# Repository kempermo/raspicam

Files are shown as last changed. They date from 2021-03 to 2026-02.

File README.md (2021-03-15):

# raspiCAM

### Setup WiFi
In order to setup WiFi with the correct credentials open the attached file "wpa_supplicant.conf" with a text editor and fill in the correct ssid and password that matches your WiFi setup.

Insert the sd-card from raspi into your computer and open it in the finder. Place the generated "wpa_supplicant.conf" onto the card.

Insert the card back to the raspi and boot. The raspi should now boot and connect to the new WiFi.

### Helpful applications
LanScan for getting the IP address of the raspi - https://apps.apple.com/de/app/lanscan/id472226235?mt=12

### Credetials for login through ssh
User: pi
Passwort: user

### Terminal command for initializing the ssh connection
ssh pi@192.168.20.248 (replace with the proper IP address of your raspi)

### Helpful terminal commands
ls - List current directory contents
cd + ... - entering a directory
cd .. - going back one directory
sudo nano + ... - opening a file in editor
sudo python3 + ... - running a python script with python3
ps aux - list current running processes
sudo kill 425 - kill the process with ID 425

### Helpful key commands
"option"+"c" - quit the current running process

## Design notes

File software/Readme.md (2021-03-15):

Last login: Sat Mar 13 20:49:38 on ttys001
mke@Bridge ~ % ssh pi@192.168.20.248         
pi@192.168.20.248's password: 
Linux raspberrypi 5.4.51+ #1333 Mon Aug 10 16:38:02 BST 2020 armv6l

The programs included with the Debian GNU/Linux system are free software;
the exact distribution terms for each program are described in the
individual files in /usr/share/doc/*/copyright.

Debian GNU/Linux comes with ABSOLUTELY NO WARRANTY, to the extent
permitted by applicable law.
Last login: Sat Mar 13 22:19:36 2021
pi@raspberrypi:~ $ ps aux
USER       PID %CPU %MEM    VSZ   RSS TTY      STAT START   TIME COMMAND
root         1  0.3  2.1  32704  8024 ?        Ss   15:35   0:08 /sbin/init splash
root         2  0.0  0.0      0     0 ?        S    15:35   0:00 [kthreadd]
root         5  0.0  0.0      0     0 ?        I    15:35   0:00 [kworker/u2:0-brcmf_wq/mmc1:0001:1]
root         6  0.0  0.0      0     0 ?        I<   15:35   0:00 [mm_percpu_wq]
root         7  0.0  0.0      0     0 ?        S    15:35   0:01 [ksoftirqd/0]
root         8  0.0  0.0      0     0 ?        S    15:35   0:00 [kdevtmpfs]
root         9  0.0  0.0      0     0 ?        I<   15:35   0:00 [netns]
root        11  0.0  0.0      0     0 ?        S    15:35   0:00 [khungtaskd]
root        12  0.0  0.0      0     0 ?        S    15:35   0:00 [oom_reaper]
root        13  0.0  0.0      0     0 ?        I<   15:35   0:00 [writeback]
root        14  0.0  0.0      0     0 ?        S    15:35   0:00 [kcompactd0]
root        28  0.0  0.0      0     0 ?        I<   15:35   0:00 [kblockd]
root        29  0.0  0.0      0     0 ?        I<   15:35   0:00 [blkcg_punt_bio]
root        30  0.0  0.0      0     0 ?        S    15:35   0:00 [watchdogd]
root        31  0.0  0.0      0     0 ?        I<   15:35   0:00 [rpciod]
root        32  0.0  0.0      0     0 ?        I<   15:35   0:00 [kworker/u3:0-hci0]
root        33  0.0  0.0      0     0 ?        I<   15:35   0:00 [xprtiod]
root        34  0.0  0.0      0     0 ?        S    15:35   0:00 [kswapd0]
root        35  0.0  0.0      0     0 ?        I<   15:35   0:00 [nfsiod]
root        36  0.0  0.0      0     0 ?        I<   15:35   0:00 [iscsi_eh]
root        37  0.0  0.0      0     0 ?        I<   15:35   0:00 [dwc_otg]
root        38  0.0  0.0      0     0 ?        I<   15:35   0:00 [DWC Notificatio]
root        40  0.1  0.0      0     0 ?        S<   15:35   0:02 [vchiq-slot/0]
root        41  0.0  0.0      0     0 ?        S<   15:35   0:00 [vchiq-recy/0]
root        42  0.0  0.0      0     0 ?        S<   15:35   0:00 [vchiq-sync/0]
root        43  0.0  0.0      0     0 ?        S    15:35   0:00 [vchiq-keep/0]
root        44  0.0  0.0      0     0 ?        S<   15:35   0:00 [SMIO]
root        46  0.0  0.0      0     0 ?        I<   15:35   0:00 [mmc_complete]
root        47  0.0  0.0      0     0 ?        I<   15:35   0:01 [kworker/0:1H-mmc_complete]
root        49  0.0  0.0      0     0 ?        S    15:35   0:00 [jbd2/mmcblk0p2-]
root        50  0.0  0.0      0     0 ?        I<   15:35   0:00 [ext4-rsv-conver]
root        51  0.0  0.0      0     0 ?        I<   15:35   0:00 [ipv6_addrconf]
root        77  0.0  1.7  15528  6588 ?        Ss   15:35   0:02 /lib/systemd/systemd-journald
root       108  0.0  1.0  18360  3832 ?        Ss   15:35   0:01 /lib/systemd/systemd-udevd
root       122  0.0  0.0      0     0 ?        S<   15:36   0:00 [SMIO]
root       127  0.0  0.0      0     0 ?        I<   15:36   0:00 [mmal-vchiq]
root       128  0.0  0.0      0     0 ?        I<   15:36   0:00 [mmal-vchiq]
root       130  0.0  0.0      0     0 ?        I<   15:36   0:00 [mmal-vchiq]
root       139  0.0  0.0      0     0 ?        I<   15:36   0:00 [mmal-vchiq]
root       140  0.0  0.0      0     0 ?        I<   15:36   0:00 [mmal-vchiq]
root       141  0.0  0.0      0     0 ?        I<   15:36   0:00 [mmal-vchiq]
root       164  0.0  0.0      0     0 ?        I<   15:36   0:00 [cfg80211]
root       165  0.0  0.0      0     0 ?        I<   15:36   0:00 [brcmf_wq/mmc1:0]
root       166  0.0  0.0      0     0 ?        S    15:36   0:00 [brcmf_wdog/mmc1]
systemd+   221  0.0  1.4  22396  5604 ?        Ssl  15:36   0:01 /lib/systemd/systemd-timesyncd
root       263  0.1  0.0      0     0 ?        S    15:36   0:03 [irq/160-gt911]
root       266  0.0  0.6   7932  2300 ?        Ss   15:36   0:00 /usr/sbin/cron -f
message+   287  0.0  0.9   6712  3636 ?        Ss   15:36   0:01 /usr/bin/dbus-daemon --system --address=s
root       292  0.0  0.3  27640  1428 ?        SLsl 15:36   0:00 /usr/sbin/rngd -r /dev/hwrng
root       301  0.0  0.5   2816  1944 ?        Ss   15:36   0:00 /sbin/dhcpcd -q -b
root       311  0.0  1.2  10724  4640 ?        Ss   15:36   0:00 /sbin/wpa_supplicant -u -s -O /run/wpa_su
avahi      319  0.1  0.7   5888  3012 ?        Ss   15:36   0:03 avahi-daemon: running [raspberrypi.local]
root       330  0.0  0.5   3676  2004 ?        SNs  15:36   0:00 /usr/sbin/alsactl -E HOME=/run/alsa -s -n
avahi      340  0.0  0.4   5756  1572 ?        S    15:36   0:00 avahi-daemon: chroot helper
root       341  0.0  2.4  60128  9364 ?        Ssl  15:36   0:01 /usr/lib/udisks2/udisksd
root       344  0.0  1.5  13024  5864 ?        Ss   15:36   0:00 /lib/systemd/systemd-logind
nobody     352  0.0  0.5   4304  2116 ?        Ss   15:36   0:00 /usr/sbin/thd --triggers /etc/triggerhapp
root       356  0.0  0.9  24736  3536 ?        Ssl  15:36   0:00 /usr/sbin/rsyslogd -n -iNONE
root       376  0.0  1.1  10984  4280 ?        Ss   15:36   0:00 wpa_supplicant -B -c/etc/wpa_supplicant/w
root       379  0.0  1.5  36880  6016 ?        Ssl  15:36   0:00 /usr/lib/policykit-1/polkitd --no-debug
root       395  0.0  0.0      0     0 ?        I    15:36   0:01 [kworker/u2:3-brcmf_wq/mmc1:0001:1]
root       400  0.0  0.8  10348  3304 ?        S    15:36   0:00 sudo python3 /home/pi/Documents/camera/ca
root       404  0.0  0.1   2124   592 ?        S    15:36   0:00 /usr/bin/hciattach /dev/serial1 bcm43xx 3
root       406  0.0  0.0      0     0 ?        I<   15:36   0:00 [kworker/u3:2-hci0]
root       411  0.0  1.5  10708  5664 ?        Ss   15:36   0:00 /usr/sbin/sshd -D
root       415  0.0  0.7  21840  2764 ?        Sl   15:36   0:00 /usr/sbin/netatalk
root       416  0.2  2.6  57100 10044 ?        S    15:36   0:04 /usr/sbin/afpd -d -F /etc/netatalk/afp.co
root       417  0.0  1.1  10076  4156 ?        S    15:36   0:00 /usr/sbin/cnid_metad -d -F /etc/netatalk/
root       425 94.8  3.6  82592 13904 ?        Rl   15:36  35:11 python3 /home/pi/Documents/camera/cameraT
root       428  0.0  1.2   9792  4656 ?        Ss   15:36   0:00 /usr/lib/bluetooth/bluetoothd
root       433  0.0  1.5  36464  5904 ?        Ssl  15:36   0:00 /usr/sbin/lightdm
root       436  0.0  1.2  26692  4756 ?        Ssl  15:36   0:00 /usr/bin/bluealsa
root       451  0.0  0.0      0     0 ?        S<   15:36   0:00 [krfcommd]
root       500  0.1  9.4 117744 35704 tty7     Ssl+ 15:36   0:02 /usr/lib/xorg/Xorg :0 -seat seat0 -auth /
root       501  0.0  0.7   5604  2728 tty1     Ss   15:36   0:00 /bin/login -f
pi         561  0.0  1.9  14712  7424 ?        Ss   15:36   0:00 /lib/systemd/systemd --user
pi         565  0.0  0.9  16828  3436 ?        S    15:36   0:00 (sd-pam)
pi         634  0.0  0.9   8468  3704 tty1     S+   15:36   0:00 -bash
root       652  0.0  1.6  29892  6392 ?        Sl   15:36   0:00 lightdm --session-child 14 17
pi         660  0.0  3.1  54076 11932 ?        Ssl  15:36   0:00 /usr/bin/lxsession -s LXDE-pi -e LXDE
pi         669  0.0  0.9   6520  3444 ?        Ss   15:36   0:00 /usr/bin/dbus-daemon --session --address=
pi         693  0.0  0.3   4504  1404 ?        Ss   15:36   0:00 /usr/bin/ssh-agent x-session-manager
pi         710  0.0  1.6  42580  6228 ?        Ssl  15:36   0:00 /usr/lib/gvfs/gvfsd
pi         720  0.0  1.4  51548  5444 ?        Sl   15:36   0:00 /usr/lib/gvfs/gvfsd-fuse /run/user/1000/g
pi         738  0.0  3.8  62224 14452 ?        S    15:36   0:00 openbox --config-file /home/pi/.config/op
pi         742  0.0  2.9  47672 11192 ?        Sl   15:36   0:00 lxpolkit
pi         746  0.3  7.4 144540 28268 ?        Sl   15:36   0:07 lxpanel --profile LXDE-pi
pi         750  0.1  5.5  71092 21112 ?        Sl   15:36   0:02 pcmanfm --desktop --profile LXDE-pi
pi         778  0.0  0.3   4504  1300 ?        Ss   15:36   0:00 /usr/bin/ssh-agent -s
pi         808  0.0  2.7  78704 10356 ?        Ssl  15:37   0:00 /usr/lib/gvfs/gvfs-udisks2-volume-monitor
pi         815  0.0  1.4  39264  5320 ?        Ssl  15:37   0:00 /usr/lib/gvfs/gvfs-goa-volume-monitor
pi         819  0.0  1.9  54164  7260 ?        Ssl  15:37   0:00 /usr/lib/gvfs/gvfs-afc-volume-monitor
pi         824  0.0  1.5  40828  5968 ?        Ssl  15:37   0:00 /usr/lib/gvfs/gvfs-gphoto2-volume-monitor
pi         828  0.0  1.4  39252  5540 ?        Ssl  15:37   0:00 /usr/lib/gvfs/gvfs-mtp-volume-monitor
pi         839  0.0  1.9  51148  7292 ?        Sl   15:37   0:00 /usr/lib/gvfs/gvfsd-trash --spawner :1.4 
pi         855  0.0  1.3  26428  5068 ?        Sl   15:37   0:00 /usr/lib/menu-cache/menu-cached /run/user
root      1297  0.0  0.0      0     0 ?        I    15:59   0:00 [kworker/0:0-events_power_efficient]
root      1346  0.0  0.0      0     0 ?        I    16:04   0:00 [kworker/0:1-events]
root      1347  0.0  0.0      0     0 ?        I<   16:04   0:00 [kworker/0:0H]
root      1409  0.0  0.0      0     0 ?        I    16:09   0:00 [kworker/0:2-events]
root      1434  0.5  1.6  12220  6372 ?        Ss   16:12   0:00 sshd: pi [priv]
pi        1468  0.2  1.1  12220  4156 ?        S    16:12   0:00 sshd: pi@pts/0
pi        1471  1.1  0.9   8464  3704 pts/0    Ss   16:12   0:00 -bash
root      1482  0.0  0.0      0     0 ?        I<   16:12   0:00 [kworker/0:2H]
root      1483  0.0  0.0      0     0 ?        I    16:12   0:00 [kworker/u2:1-brcmf_wq/mmc1:0001:1]
pi        1484  0.0  0.6   9772  2552 pts/0    R+   16:13   0:00 ps aux
pi@raspberrypi:~ $ sudo kill 425
pi@raspberrypi:~ $ kill 425
-bash: kill: (425) - Kein passender Prozess gefunden
pi@raspberrypi:~ $ ls
Bookshelf  Desktop  Documents  Downloads  Music  Pictures  Pimoroni  Public  sketchbook  Templates  test.jpg  Videos
pi@raspberrypi:~ $ ls
Bookshelf  Desktop  Documents  Downloads  Music  Pictures  Pimoroni  Public  sketchbook  Templates  test.jpg  Videos
pi@raspberrypi:~ $ cd Documents
pi@raspberrypi:~/Documents $ ls
camera
pi@raspberrypi:~/Documents $ cd camera
pi@raspberrypi:~/Documents/camera $ ls
 cameraTest.py                           'IMG_2020-12-29 21:21:28.433020_2_.jpg'  'pic_2020-12-28 22:55:26.054270_3_.jpg'
 grid.png                                'IMG_2020-12-29 21:21:28.433020_3_.jpg'  'pic_2020-12-28 22:55:26.054270_4_.jpg'
 IMG_2020-12-29_0_.jpg                    lib_oled96                              'pic_2020-12-28 22:56:33.998395_0_.jpg'
 IMG_2020-12-29_1_.jpg                   'pic2020-12-28 22:48:20.859667.jpg'      'pic_2020-12-28 22:56:33.998395_1_.jpg'
'IMG_2020-12-29 20:57:09.884041_0_.jpg'  'pic2020-12-28 22:52:31.490010.jpg'       picameraPygame.py
'IMG_2020-12-29 21:15:53.772426_0_.jpg'  'pic_2020-12-28 22:55:26.054270_0_.jpg'   python-multitouch
'IMG_2020-12-29 21:21:28.433020_0_.jpg'  'pic_2020-12-28 22:55:26.054270_1_.jpg'   stats.py
'IMG_2020-12-29 21:21:28.433020_1_.jpg'  'pic_2020-12-28 22:55:26.054270_2_.jpg'   stats.py.save
pi@raspberrypi:~/Documents/camera $ cd ..
pi@raspberrypi:~/Documents $ cd camera
pi@raspberrypi:~/Documents/camera $ sudo nano cameraTest.py
pi@raspberrypi:~/Documents/camera $ sudo nano cameraTest.py
pi@raspberrypi:~/Documents/camera $ sudo python3 cameraTest.py
^CTraceback (most recent call last):
  File "cameraTest.py", line 79, in <module>
    disp.image(image)
  File "/usr/local/lib/python3.7/dist-packages/adafruit_framebuf.py", line 445, in image
    self.pixel(x, y, 1)  # only write if pixel is true
  File "/usr/local/lib/python3.7/dist-packages/adafruit_framebuf.py", line 248, in pixel
    self.format.set_pixel(self, x, y, color)
  File "/usr/local/lib/python3.7/dist-packages/adafruit_framebuf.py", line 92, in set_pixel
    framebuf.buf[index] = (framebuf.buf[index] & ~(0x01 << offset)) | (
KeyboardInterrupt
pi@raspberrypi:~/Documents/camera $ sudo python3 cameraTest.py
^CTraceback (most recent call last):
  File "cameraTest.py", line 80, in <module>
    disp.show()
  File "/usr/local/lib/python3.7/dist-packages/adafruit_ssd1306.py", line 194, in show
    self.write_framebuf()
  File "/usr/local/lib/python3.7/dist-packages/adafruit_ssd1306.py", line 261, in write_framebuf
    self.i2c_device.write(self.buffer)
  File "/usr/local/lib/python3.7/dist-packages/adafruit_bus_device/i2c_device.py", line 84, in write
    self.i2c.writeto(self.device_address, buf, start=start, end=end)
  File "/usr/local/lib/python3.7/dist-packages/busio.py", line 115, in writeto
    return self._i2c.writeto(address, memoryview(buffer)[start:end], stop=stop)
  File "/usr/local/lib/python3.7/dist-packages/adafruit_blinka/microcontroller/generic_linux/i2c.py", line 49, in writeto
    self._i2c_bus.write_bytes(address, buffer[start:end])
  File "/usr/local/lib/python3.7/dist-packages/Adafruit_PureIO/smbus.py", line 308, in write_bytes
    self._device.write(buf)
KeyboardInterrupt
pi@raspberrypi:~/Documents/camera $ sudo nano example.py
pi@raspberrypi:~/Documents/camera $ ls
 cameraTest.py                           'IMG_2020-12-29 21:21:28.433020_2_.jpg'  'pic_2020-12-28 22:55:26.054270_3_.jpg'
 grid.png                                'IMG_2020-12-29 21:21:28.433020_3_.jpg'  'pic_2020-12-28 22:55:26.054270_4_.jpg'
 IMG_2020-12-29_0_.jpg                    lib_oled96                              'pic_2020-12-28 22:56:33.998395_0_.jpg'
 IMG_2020-12-29_1_.jpg                   'pic2020-12-28 22:48:20.859667.jpg'      'pic_2020-12-28 22:56:33.998395_1_.jpg'
'IMG_2020-12-29 20:57:09.884041_0_.jpg'  'pic2020-12-28 22:52:31.490010.jpg'       picameraPygame.py
'IMG_2020-12-29 21:15:53.772426_0_.jpg'  'pic_2020-12-28 22:55:26.054270_0_.jpg'   python-multitouch
'IMG_2020-12-29 21:21:28.433020_0_.jpg'  'pic_2020-12-28 22:55:26.054270_1_.jpg'   stats.py
'IMG_2020-12-29 21:21:28.433020_1_.jpg'  'pic_2020-12-28 22:55:26.054270_2_.jpg'   stats.py.save
pi@raspberrypi:~/Documents/camera $ sudo nano cameraTest.py

  GNU nano 3.2                                              cameraTest.py                                              Verändert  

from picamera import PiCamera
from time import sleep
from datetime import datetime
import smbus #needed for i2c communication to arduino
from ft5406 import Touchscreen
from board import SCL, SDA #another i2c library needed to interface with the small oled
import busio #i2c for small oled
from PIL import Image, ImageDraw, ImageFont #small oled
import adafruit_ssd1306 #small oled

bus =  smbus.SMBus(11)
address = 0x08 #refering to the address of the arduino

#small oled
# Create the I2C interface.
i2c = busio.I2C(SCL, SDA)
# to the right size for your display!
disp = adafruit_ssd1306.SSD1306_I2C(128, 32, i2c)

# Clear display.
disp.fill(0)
disp.show()

width = disp.width
height = disp.height
image = Image.new("1", (width, height))

# Get drawing object to draw on image.
draw = ImageDraw.Draw(image)

font = ImageFont.load_default()

camera = PiCamera()

shutterFlag = True

timestamp=datetime.now().date()
pictureIndex = 0

ts = Touchscreen(device="Goodix Capacitive TouchScreen")

def picture():
        camera.capture('IMG_'+str(timestamp)+'_'+str(pictureIndex)+'_'+'.jpg') #taking the picture

def translate(value, leftMin, leftMax, rightMin, rightMax):
    # Figure out how 'wide' each range is
    leftSpan = leftMax - leftMin
    rightSpan = rightMax - rightMin

    # Convert the left range into a 0-1 range (float)
    valueScaled = float(value - leftMin) / float(leftSpan)

    # Convert the 0-1 range into a value in the right range.
    return rightMin + (valueScaled * rightSpan)

camera.rotation = 270
camera.start_preview()
camera.preview_window = (0,0,800,480)
#camera.annotate_text = "Effect: Information"

while shutterFlag:
        draw.rectangle((0, 0, width, height), outline=0, fill=0)
        number = bus.read_byte(address)
        draw.text((0, 0), "Number: " + str(pictureIndex), font=font, fill=255)
        draw.text((0, 8), "Brightness: " + str(camera.brightness), font=font, fill=255)
        draw.text((0, 16), "Contrast: " + str(camera.contrast), font=font, fill=255)
        for touch in ts.poll():
                #print(touch.slot, touch.id, touch.valid, touch.x, touch.y)
                if touch.slot == 0:
                        camera.brightness = int(translate(touch.x,0,800,0,100))
                        camera.contrast = int(translate(touch.y,0,480,-100,100))
                if touch.slot == 1 and touch.valid == True:
                        camera.saturation = int(translate(touch.x,0,800,-100,100))
        if number == 0:
                print("read", number)
                picture()
                pictureIndex+=1
                sleep(1)
        disp.image(image)
        disp.show()
#camera.stop_preview()

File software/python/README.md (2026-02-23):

# raspiCAM – Python Software

## Hardware

| Component | Details |
|---|---|
| Raspberry Pi | Pi 4 / Pi Zero 2 W |
| Display | HyperPixel 4.0 (480×800, DRM/KMS) |
| Camera | OV5647 (connected via CSI) |
| Small OLED | 128×32 SSD1306 via I2C |
| Arduino | I2C address `0x08`, connected on bus 11 |

---

## Files

| File | Purpose |
|---|---|
| `bareMinimum.py` | Main camera application |
| `camera.service` | systemd service for autostart |
| `99-i2c-alias.rules` | udev rule to fix I2C bus numbering |

---

## Raspberry Pi Setup

### 1. Boot mode
The app uses `Preview.DRM` which requires **exclusive access to the display**.
Boot the Pi to **CLI** (not desktop):
```
sudo raspi-config nonint do_boot_behaviour B2
```

### 2. I2C bus alias (persistent)
On Raspberry Pi OS Bookworm the I2C bus is numbered `i2c-11` instead of the expected `i2c-1`. The udev rule creates a persistent symlink automatically on every boot:

```bash
sudo cp 99-i2c-alias.rules /etc/udev/rules.d/
sudo udevadm control --reload-rules
```

### 3. Autostart via systemd
Install the service so the camera starts automatically on every boot:

```bash
sudo cp camera.service /etc/systemd/system/
sudo systemctl daemon-reload
sudo systemctl enable camera.service
sudo systemctl start camera.service
```

Check status:
```bash
sudo systemctl status camera.service
```

View logs:
```bash
sudo journalctl -u camera.service -n 50
```

---

## Running manually

```bash
python3 /home/pi/Documents/camera/bareMinimum.py
```

Required files on the Pi at `/home/pi/Documents/camera/`:
- `bareMinimum.py`
- `uiImage.png` (UI overlay, 480×800 RGBA)
- `ESKlarheitGrotesk-Bold.ttf` (font for OLED display)

---

## Known issues & notes

- **I2C bus renumbering** – Pi OS Bookworm renamed `i2c-1` to `i2c-11`. The udev rule in this repo handles this automatically.
- **DRM preview + desktop conflict** – `Preview.DRM` takes exclusive control of the display. If a Wayland compositor (labwc) is running it will conflict and the preview will be invisible. Always boot to CLI.
- **Color format** – The camera stream must be configured as `XRGB8888`. Using the default `XBGR8888` results in red and blue channels being swapped on the HyperPixel display.
- **systemd WorkingDirectory** – The service requires `WorkingDirectory=/home/pi` so that `lgpio` can create its temporary notification files. Without this the service crashes silently in a restart loop.

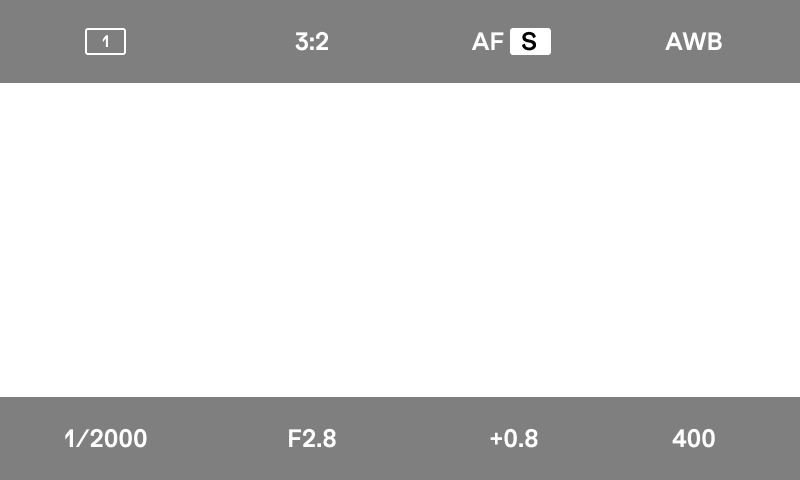
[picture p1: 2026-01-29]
software/python/uiImage.png

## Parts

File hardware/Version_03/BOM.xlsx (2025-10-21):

Check | Qty | Part | Value | Type | URL
 | 5 | C1,C6,C8,C9,C10 | 10uF | Cap | https://www.mouser.de/ProductDetail/KEMET/C0805C106M8PACTU?qs=Zpyg6gQUYs10fYWfqjpq2Q%3D%3D
 | 1 | C2 | 2.2uF | Cap
 | 2 | C3,C7 | 1uF | Cap | https://www.mouser.de/ProductDetail/KEMET/C0805C105K8RACTU?qs=Nnkldhwoc37vJEa%2FkGSWlQ%3D%3D
 | 4 | C4,C11,C12,C13 | 0.1uF | Cap
 | 1 | C5 | 100uF | Cap
 | 2 | R1,R3 | 1.87mOhm | Res
 | 2 | R2,R13 | 340kOhm | Res
 | 1 | R4 | 200kOhm | Res
 | 1 | R8 | 2kOhm | Res
 | 2 | R9,R17 | 10kOhm | Res
 | 1 | R16 | 390kOhm | Res
 | 1 | U1 | TPS61090RSAR | Vreg | https://www.mouser.de/ProductDetail/Texas-Instruments/TPS61090RSAR?qs=Gse6rAGbi7%2FbGTQiY2PrFA%3D%3D
 | 1 | U2 | MCP73831T | Charge Controler
 | 1 | U3 | ATMEGA328 | Microcontroller | https://www.mouser.de/ProductDetail/Microchip-Technology/ATMEGA168V-10AUR?qs=JV7lzlMm3yL1LUNczo0T2w%3D%3D
 | 1 | L1 | VLC5045-6.8uH | Inductor
 | 1 | IC5 | APX803 | Transistor
 | 2 | CAM_BOTTOM, CAM_TOP | MOLEX_54548-2271MOLEX_54548-2271_0_0
 | 1 | Q2 | 8Mhz | Resonator
 | 2 |  | 54548-1472 | Connector | https://www.mouser.de/ProductDetail/Molex/54548-1472?qs=vvQtp7zwQdOn9j3kc9uPug%3D%3D

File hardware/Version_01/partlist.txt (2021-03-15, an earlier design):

Partlist

Exported from Camera.sch at 05.01.21 22:15

EAGLE Version 9.6.2 Copyright (c) 1988-2020 Autodesk, Inc.

Assembly variant: 

Part     		Value                          Device                         Package                    Library             Sheet

B1       		1.8-5V                         BATTERY                        JSTPH2                     microbuilder        1

C2       		2.2uF                          CAP_CERAMIC0805-NOOUTLINE      0805-NO                    microbuilder        1
C3+C7      		1uF                            CAP_CERAMIC0805-NOOUTLINE      0805-NO                    microbuilder        1
C5       		100uF/6V                       CAP_TANTALUMB/3528_REFLOW      EIA3528-21/B-R             microbuilder        1
C1+C6+C8+C9+C10       	10uF                           CAP_CERAMIC0805-NOOUTLINE      0805-NO                    microbuilder        1
C4+C11+C12+C13      	0.1uF                          CAP_CERAMIC0805-NOOUTLINE      0805-NO                    microbuilder        1

IC5      		APX803                         AXP083-SAG                     SOT23                      adafruit            1

J1                                      	       CONN_06SMD-FEMALE-V2           1X06-SMD-FEMALE            SparkFun-Connectors 1
J2                                      	       CONN_06SMD-FEMALE-V2           1X06-SMD-FEMALE            SparkFun-Connectors 1
J3                                      	       CONN_06SMD-FEMALE-V2           1X06-SMD-FEMALE            SparkFun-Connectors 1

L1       		VLC5045-6.8uH                  INDUCTORTDK_VLC5045            INDUCTOR_5X5MM_TDK_VLC5045 microbuilder        1
LCD1     		OLED 128x32                    DISP_OLED_UG-2832HSWEG02       UG-2832HSWEG02_WRAPUNDER   microbuilder        1
Q2       		8MHz                           RESONATORSMD                   RESONATOR-SMD              SparkFun            1

R1+R3       		1.87Mohm                       RESISTOR0805_NOOUTLINE         0805-NO                    microbuilder        1
R4       		200K                           RESISTOR0805_NOOUTLINE         0805-NO                    microbuilder        1
R8       		2k                             RESISTOR0805_NOOUTLINE         0805-NO                    microbuilder        1
R9+R17   		10K                            RESISTOR0805_NOOUTLINE         0805-NO                    microbuilder        1
R5+R10   		5.1k                           RESISTOR0805_NOOUTLINE         0805-NO                    microbuilder        1
R2+R13      		340K                           RESISTOR0805_NOOUTLINE         0805-NO                    microbuilder        1
R16      		390K                           RESISTOR0805_NOOUTLINE         0805-NO                    microbuilder        1

S1                      SWITCH-SPDT-SMD-RIGHT-ANGLE    SWITCH_SPST_SMD_A          				 SparkFun-Switches   1
S2       		MOMENTARY-SWITCH-SPST-SMD-12MM MOMENTARY-SWITCH-SPST-SMD-12MM TACTILE_SWITCH_SMD_12MM    SparkFun-Switches   1
U1       		TPS61090RSAR                   VREG_TPS6103X                  PVQFN-16                   microbuilder        1
U2       		MCP73831T-2ACI/OT              MCP73831/2                     SOT23-5                    microbuilder        1
U3       		ATMEGA328                      ATMEGA168                      TQFP32-08                  SparkFun            1
X3                          			       USB_C                          USB_C_CUSB31-CFM2AX-01-X   microbuilder        1

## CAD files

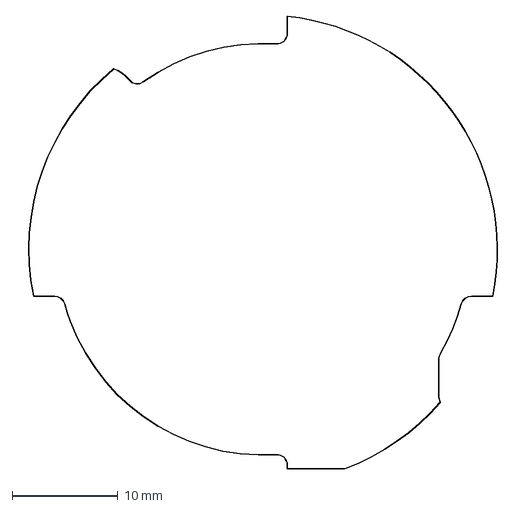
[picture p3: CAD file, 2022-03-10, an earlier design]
hardware/Version_02/PCB_final.dxf
46.4 x 42.9 mm

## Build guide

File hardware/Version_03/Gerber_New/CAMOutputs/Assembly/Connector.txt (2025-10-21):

Partlist exported from /Users/moritzkemper/Documents/GitHub/Phoenix/raspicam/hardware/Version_03/Connector.sch at 20.10.25 13:50

Qty Value       Device                   Package                  Parts Description                                      MF           MPN        OC_FARNELL OC_NEWARK POPULARITY
1   52745-1490  52745-1490               52745-1490               X3    FFC/FPC-to-Board  0.50mm (.020") SMT Top Contact WALDOM/MOLEX 52745-1490 unknown    38C9888   0         
1   OLED 128x32 DISP_OLED_UG-2832HSWEG02 UG-2832HSWEG02_WRAPUNDER LCD2  128x32 I2C 0.91" Monochrome OLED Display

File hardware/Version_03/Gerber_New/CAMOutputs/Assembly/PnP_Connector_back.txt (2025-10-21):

X3	3.60	7.87	270.00	52745-1490	52745-1490

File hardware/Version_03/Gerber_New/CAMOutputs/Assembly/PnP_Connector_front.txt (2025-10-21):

LCD2	5.34	7.87	180.00	OLED 128x32	UG-2832HSWEG02_WRAPUNDER

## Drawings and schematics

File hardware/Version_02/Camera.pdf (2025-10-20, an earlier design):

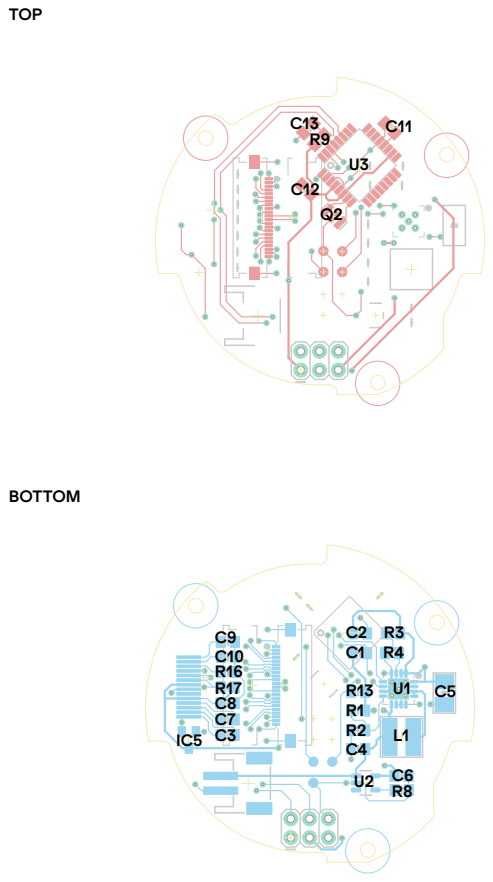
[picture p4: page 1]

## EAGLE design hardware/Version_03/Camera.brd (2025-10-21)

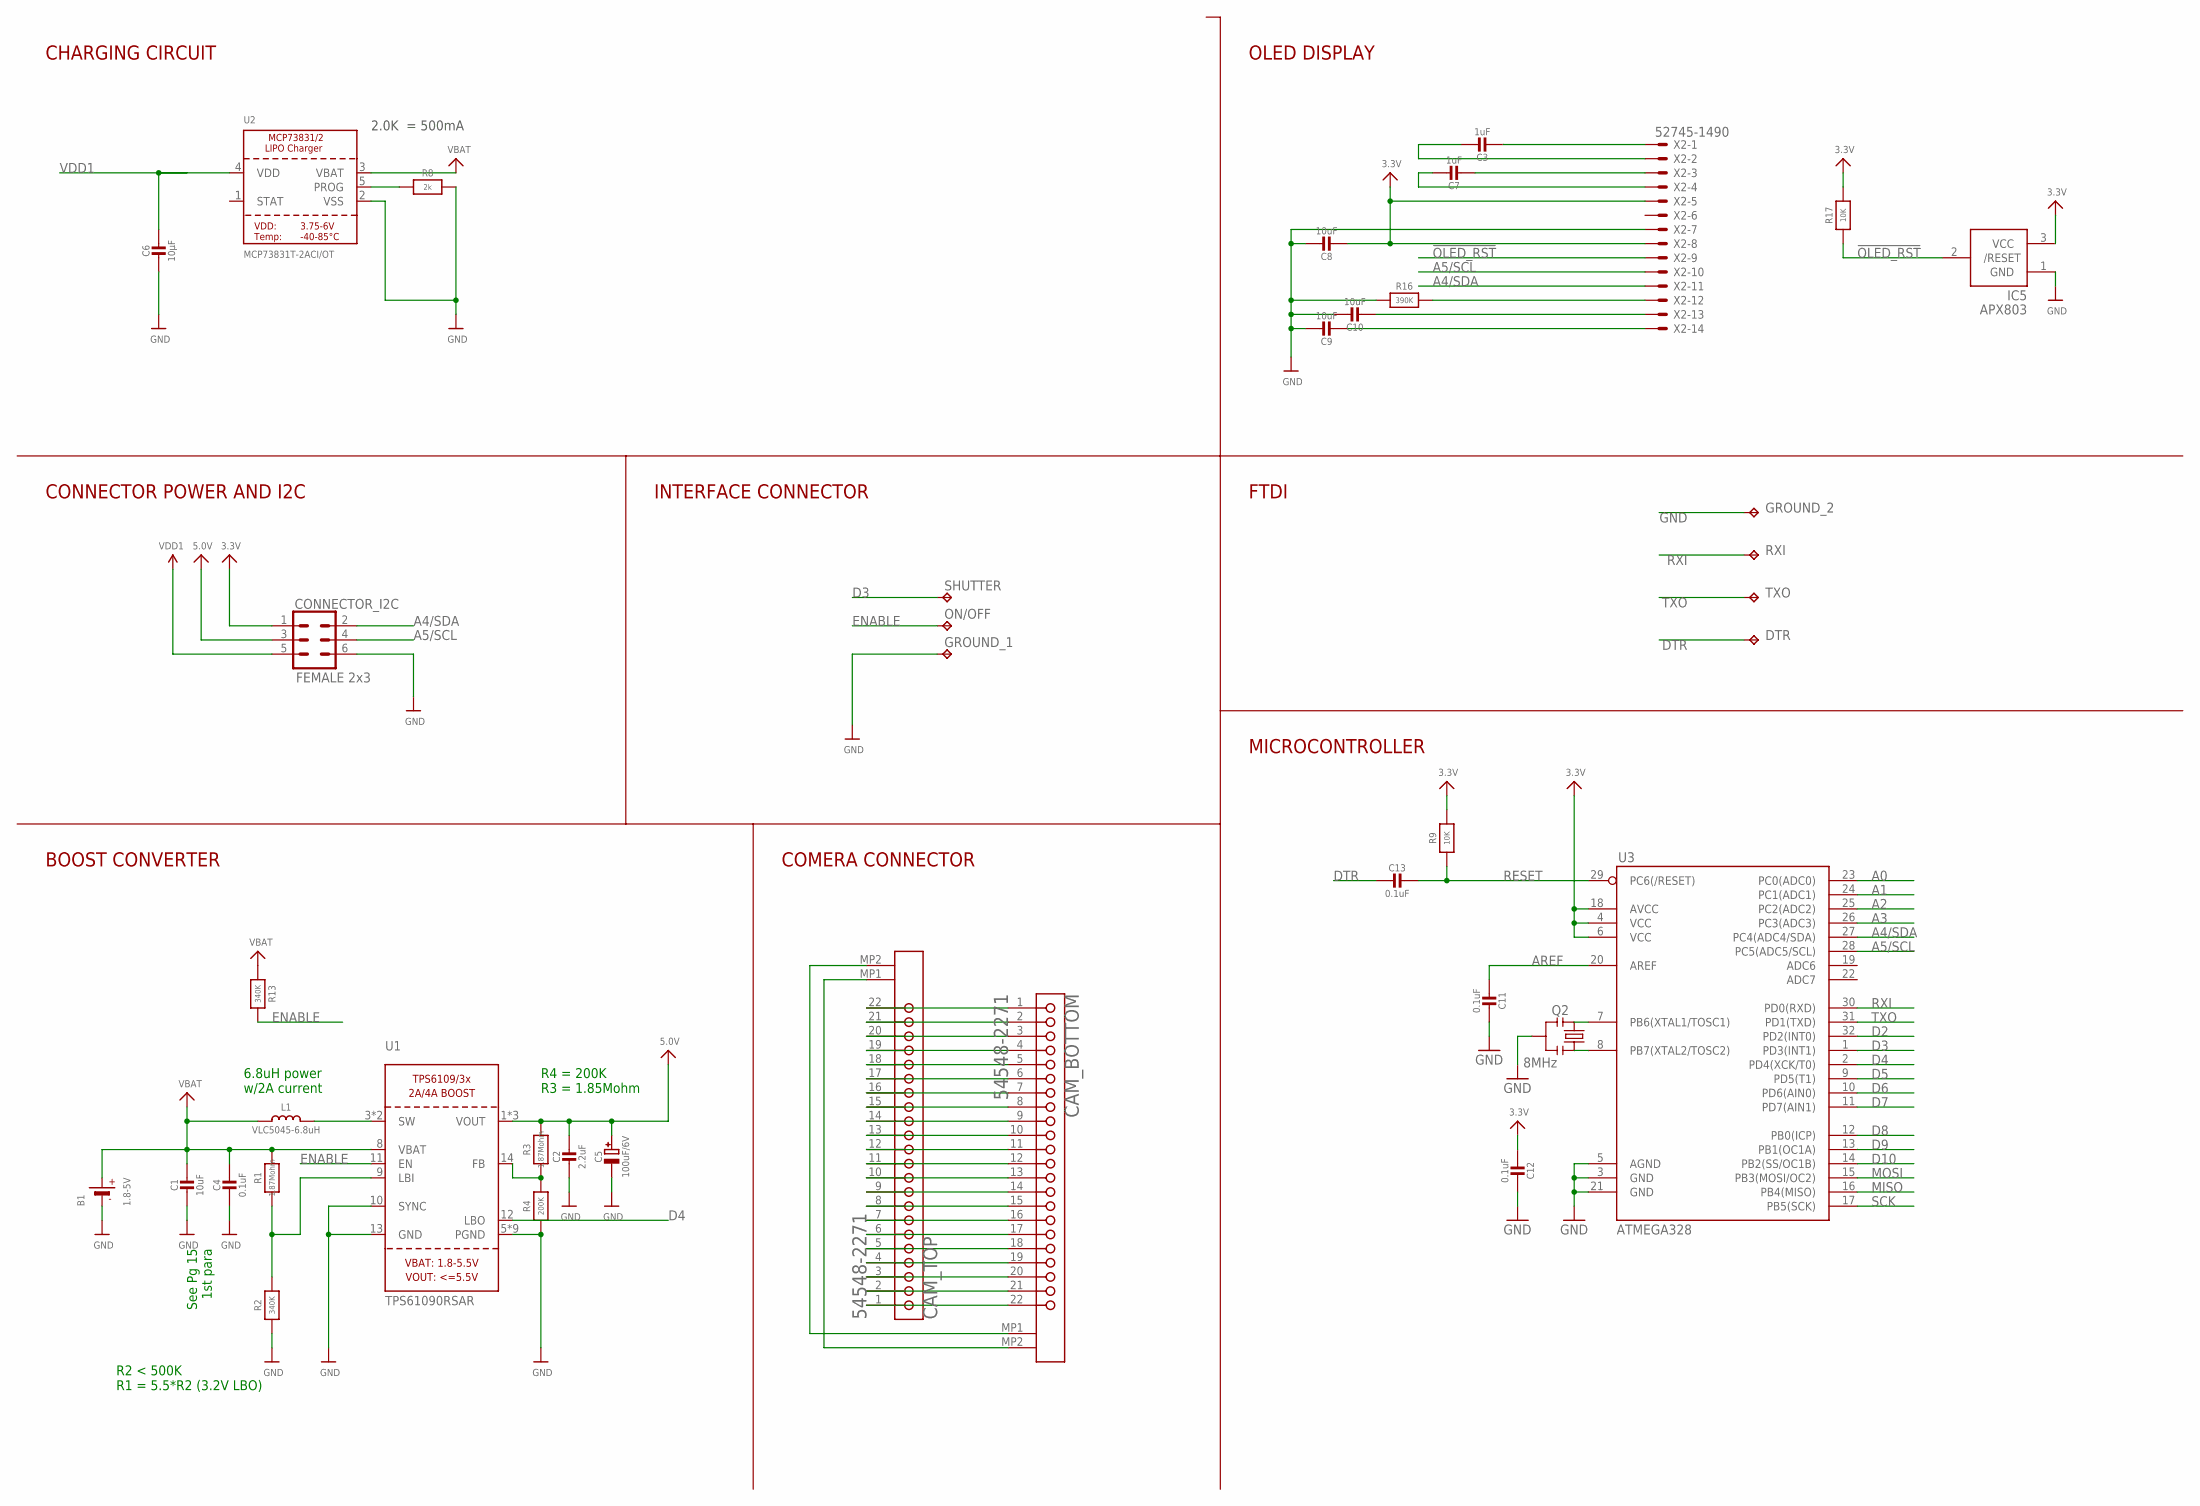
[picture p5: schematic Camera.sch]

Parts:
B1: 1.8-5V; JSTPH2
C1, C8, C9, C10: 10uF; 0805-NO
C2: 2.2uF; 0805-NO
C3, C7: 1uF; 0805-NO
C4, C11, C12, C13: 0.1uF; 0805-NO
C5: 100uF/6V; EIA3528-21/B-R
C6: 10µF; 0805-NO
CAM_BOTTOM: MOLEX_54548-2271MOLEX_54548-2271_0_0; MOLEX_54548-2271_0
CAM_TOP: MOLEX_54548-2271MOLEX_54548-2271_0_0; MOLEX_54548-2271_0
CONNECTOR_I2C: FEMALE 2x3; 2X3
DTR: TPB1,27; B1,27
GROUND_1, GROUND_2: TPB1,27; B1,27
IC5: APX803; SOT23
L1: VLC5045-6.8uH; INDUCTOR_5X5MM_TDK_VLC5045
ON/OFF: TPB1,27; B1,27
Q2: 8MHz; RESONATOR-SMD
R1, R3: 1.87Mohm; 0805-NO
R2, R13: 340K; 0805-NO
R4: 200K; 0805-NO
R8: 2k; 0805-NO
R9, R17: 10K; 0805-NO
R16: 390K; 0805-NO
RXI: TPB1,27; B1,27
SHUTTER: TPB1,27; B1,27
TXO: TPB1,27; B1,27
U1: TPS61090RSAR; PVQFN-16
U2: MCP73831T-2ACI/OT; SOT23-5
U3: ATMEGA328; TQFP32-08
X2: 52745-1490

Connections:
3.3V: C8.2, C12.2, CONNECTOR_I2C.1, IC5.3 (VCC), R9.2, R17.2, U3.4 (VCC), U3.6 (VCC), U3.18 (AVCC), X2.5, X2.8
5.0V: C2.1, C5.+, CONNECTOR_I2C.3, R3.2, U1.1 (VOUT), U1.15 (VOUT), U1.16 (VOUT)
!OLED_RST: IC5.2 (/RESET), R17.1, X2.9
A0: U3.23 (PC0(ADC0))
A1: U3.24 (PC1(ADC1))
A2: U3.25 (PC2(ADC2))
A3: U3.26 (PC3(ADC3))
A4/SDA: CONNECTOR_I2C.2, U3.27 (PC4(ADC4/SDA)), X2.11
A5/SCL: CONNECTOR_I2C.4, U3.28 (PC5(ADC5/SCL)), X2.10
AREF: C11.2, U3.20 (AREF)
D2: U3.32 (PD2(INT0))
D3: SHUTTER.TP, U3.1 (PD3(INT1))
D4: U1.12 (LBO), U3.2 (PD4(XCK/T0))
D5: U3.9 (PD5(T1))
D6: U3.10 (PD6(AIN0))
D7: U3.11 (PD7(AIN1))
D8: U3.12 (PB0(ICP))
D9: U3.13 (PB1(OC1A))
D10: U3.14 (PB2(SS/OC1B))
DTR: C13.2, DTR.TP
ENABLE: ON/OFF.TP, R13.2, U1.11 (EN)
GND: B1.1 (-), C1.2, C2.2, C4.2, C5.-, C6.2, C8.1, C9.1, C10.1, C11.1, C12.1, CONNECTOR_I2C.6, GROUND_1.TP, GROUND_2.TP, IC5.1 (GND), Q2.2, R2.1, R4.1, R8.2, R16.1, U1.5 (PGND), U1.6 (PGND), U1.7 (PGND), U1.10 (SYNC), U1.13 (GND), U1.P$18 (PGND), U1.P$19 (PGND), U1.P$20 (PGND), U1.P$21 (PGND), U1.P$22 (PGND), U1.THERMAL (PGND), U2.2 (VSS), U3.3 (GND), U3.5 (AGND), U3.21 (GND), X2.7
MISO: U3.16 (PB4(MISO))
MOSI: U3.15 (PB3(MOSI/OC2))
unnamed: L1.P$2 (2), U1.3 (SW), U1.4 (SW)
unnamed: CAM_BOTTOM.MP1, CAM_TOP.MP2
unnamed: R1.1, R2.2, U1.9 (LBI)
unnamed: CAM_BOTTOM.MP2, CAM_TOP.MP1
unnamed: R3.1, R4.2, U1.14 (FB)
unnamed: CAM_BOTTOM.1, CAM_TOP.22
unnamed: CAM_BOTTOM.2, CAM_TOP.21
unnamed: R8.1, U2.5 (PROG)
unnamed: CAM_BOTTOM.3, CAM_TOP.20
unnamed: CAM_BOTTOM.4, CAM_TOP.19
unnamed: C3.2, X2.1
unnamed: C3.1, X2.2
unnamed: C7.2, X2.3
unnamed: C7.1, X2.4
unnamed: C10.2, X2.13
unnamed: R16.2, X2.12
unnamed: C9.2, X2.14
unnamed: Q2.1, U3.8 (PB7(XTAL2/TOSC2))
unnamed: Q2.3, U3.7 (PB6(XTAL1/TOSC1))
unnamed: CAM_BOTTOM.5, CAM_TOP.18
unnamed: CAM_BOTTOM.6, CAM_TOP.17
unnamed: CAM_BOTTOM.7, CAM_TOP.16
unnamed: CAM_BOTTOM.8, CAM_TOP.15
unnamed: CAM_BOTTOM.9, CAM_TOP.14
unnamed: CAM_BOTTOM.10, CAM_TOP.13
unnamed: CAM_BOTTOM.11, CAM_TOP.12
unnamed: CAM_BOTTOM.12, CAM_TOP.11
unnamed: CAM_BOTTOM.13, CAM_TOP.10
unnamed: CAM_BOTTOM.14, CAM_TOP.9
unnamed: CAM_BOTTOM.15, CAM_TOP.8
unnamed: CAM_BOTTOM.16, CAM_TOP.7
unnamed: CAM_BOTTOM.17, CAM_TOP.6
unnamed: CAM_BOTTOM.18, CAM_TOP.5
unnamed: CAM_BOTTOM.19, CAM_TOP.4
unnamed: CAM_BOTTOM.20, CAM_TOP.3
unnamed: CAM_BOTTOM.21, CAM_TOP.2
unnamed: CAM_BOTTOM.22, CAM_TOP.1
RESET: C13.1, R9.1, U3.29 (PC6(/RESET))
RXI: RXI.TP, U3.30 (PD0(RXD))
SCK: U3.17 (PB5(SCK))
TXO: TXO.TP, U3.31 (PD1(TXD))
VBAT: B1.2 (+), C1.1, C4.1, L1.P$1 (1), R1.2, R13.1, U1.8 (VBAT), U2.3 (VBAT)
VDD1: C6.1, CONNECTOR_I2C.5, U2.4 (VDD)

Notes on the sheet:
See Pg 15 1st para
6.8uH power w/2A current
R2 < 500K R1 = 5.5*R2 (3.2V LBO)
R4 = 200K R3 = 1.85Mohm
2.0K = 500mA
CHARGING CIRCUIT
CONNECTOR POWER AND I2C
INTERFACE CONNECTOR
BOOST CONVERTER
MICROCONTROLLER
OLED DISPLAY
COMERA CONNECTOR
FTDI

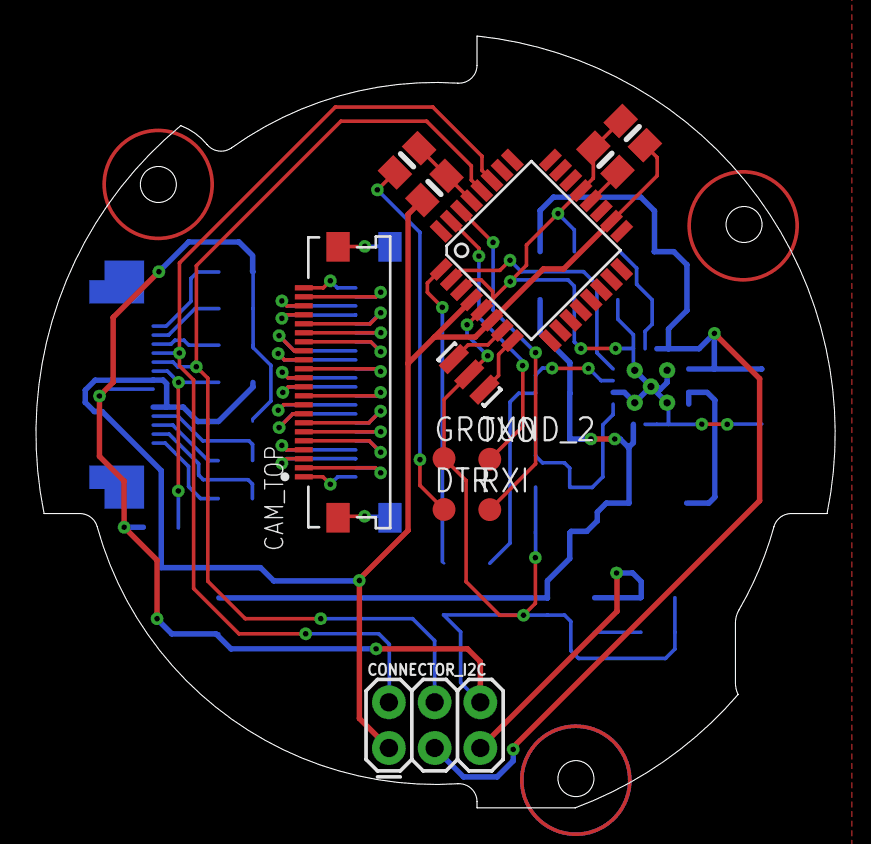
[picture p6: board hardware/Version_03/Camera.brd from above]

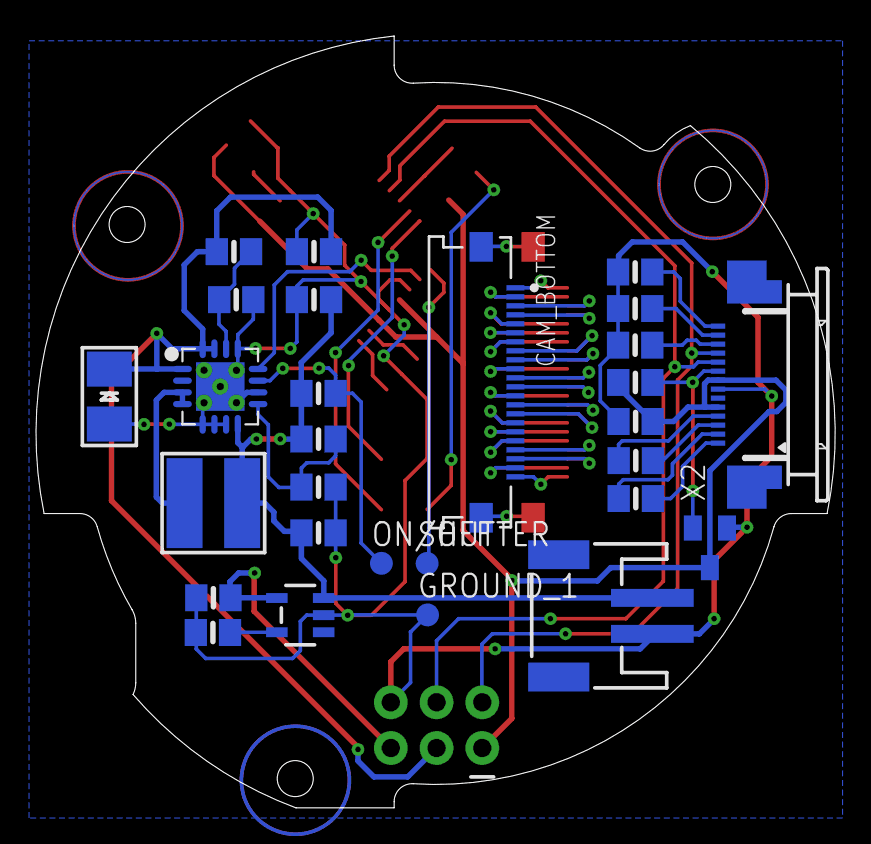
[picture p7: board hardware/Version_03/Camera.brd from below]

Board: 2 copper layers, 44.4 x 42.9 mm, 40 parts (28 on the bottom side), 53 nets.

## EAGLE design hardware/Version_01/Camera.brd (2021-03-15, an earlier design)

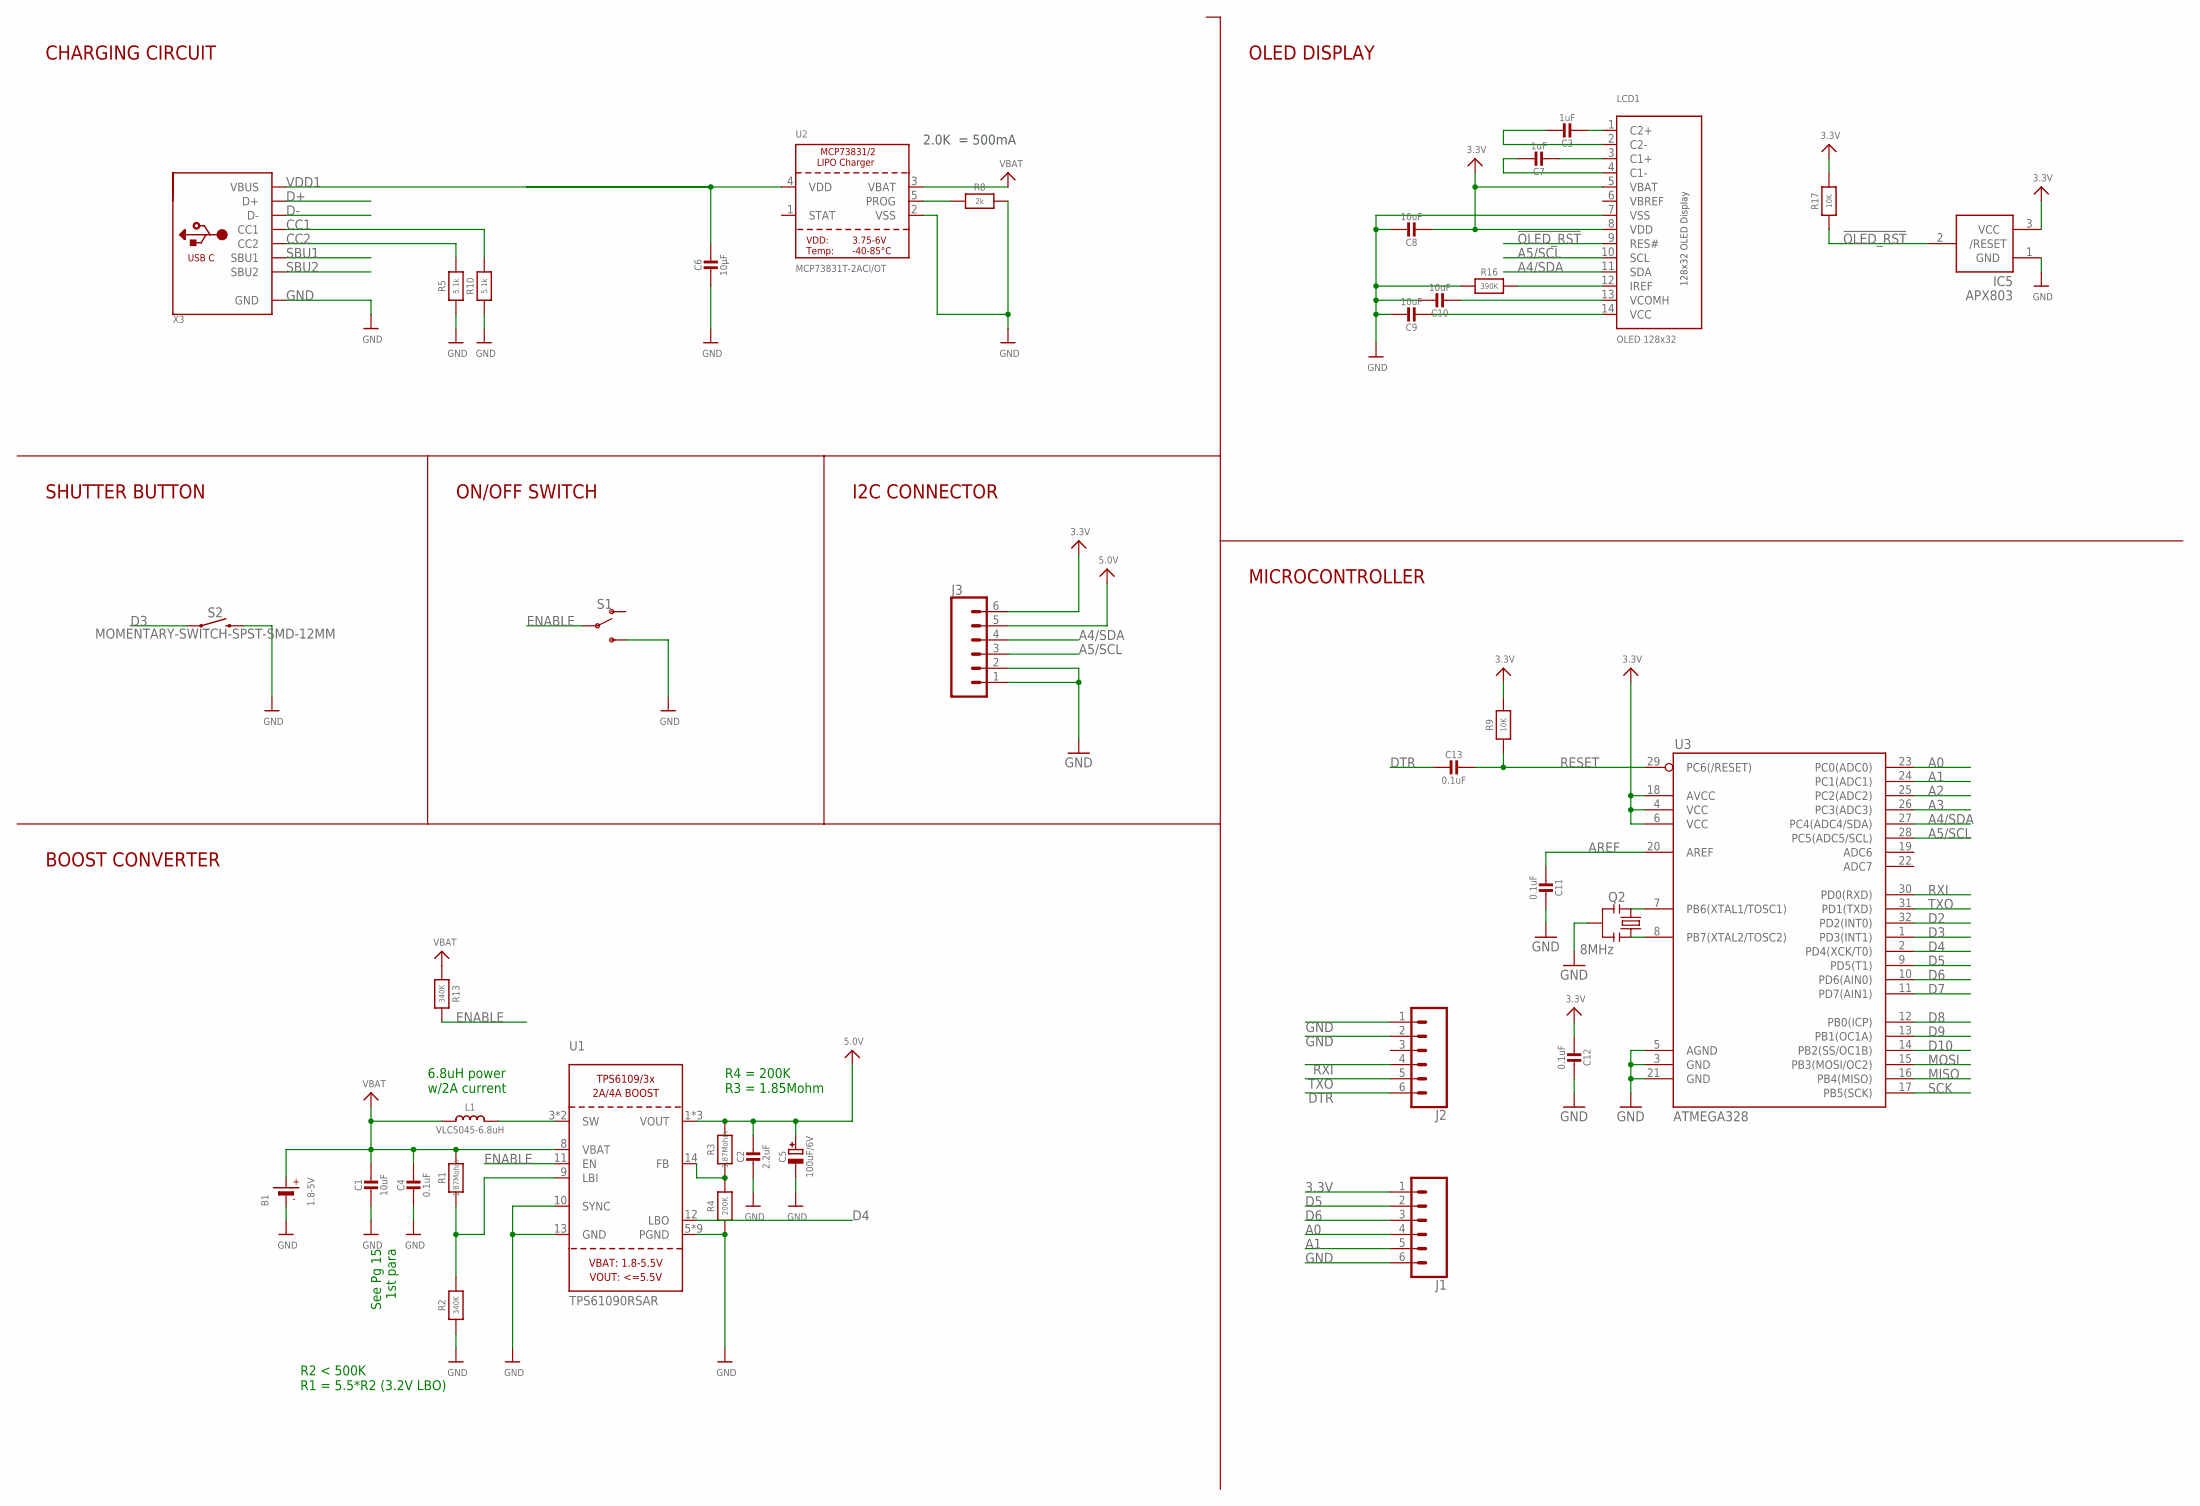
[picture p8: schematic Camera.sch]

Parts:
B1: 1.8-5V; JSTPH2
C1, C8, C9, C10: 10uF; 0805-NO
C2: 2.2uF; 0805-NO
C3, C7: 1uF; 0805-NO
C4, C11, C12, C13: 0.1uF; 0805-NO
C5: 100uF/6V; EIA3528-21/B-R
C6: 10µF; 0805-NO
IC5: APX803; SOT23
J1, J2, J3: CONN_06SMD-FEMALE-V2; 1X06-SMD-FEMALE
L1: VLC5045-6.8uH; INDUCTOR_5X5MM_TDK_VLC5045
LCD1: OLED 128x32; UG-2832HSWEG02_WRAPUNDER
Q2: 8MHz; RESONATOR-SMD
R1, R3: 1.87Mohm; 0805-NO
R2, R13: 340K; 0805-NO
R4: 200K; 0805-NO
R5, R10: 5.1k; 0805-NO
R8: 2k; 0805-NO
R9, R17: 10K; 0805-NO
R16: 390K; 0805-NO
S1: SWITCH-SPDT-SMD-RIGHT-ANGLE; SWITCH_SPST_SMD_A
S2: MOMENTARY-SWITCH-SPST-SMD-12MM; TACTILE_SWITCH_SMD_12MM
U1: TPS61090RSAR; PVQFN-16
U2: MCP73831T-2ACI/OT; SOT23-5
U3: ATMEGA328; TQFP32-08
X3: USB_C; USB_C_CUSB31-CFM2AX-01-X

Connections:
3.3V: C8.2, C12.2, IC5.3 (VCC), J1.1, J3.6, LCD1.5 (VBAT), LCD1.8 (VDD), R9.2, R17.2, U3.4 (VCC), U3.6 (VCC), U3.18 (AVCC)
5.0V: C2.1, C5.+, J3.5, R3.2, U1.1 (VOUT), U1.15 (VOUT), U1.16 (VOUT)
!OLED_RST: IC5.2 (/RESET), LCD1.9 (RES#), R17.1
A0: J1.4, U3.23 (PC0(ADC0))
A1: J1.5, U3.24 (PC1(ADC1))
A2: U3.25 (PC2(ADC2))
A3: U3.26 (PC3(ADC3))
A4/SDA: J3.4, LCD1.11 (SDA), U3.27 (PC4(ADC4/SDA))
A5/SCL: J3.3, LCD1.10 (SCL), U3.28 (PC5(ADC5/SCL))
AREF: C11.2, U3.20 (AREF)
CC1: R10.2, X3.A5 (CC1)
CC2: R5.2, X3.B5 (CC2)
D2: U3.32 (PD2(INT0))
D3: S2.1, U3.1 (PD3(INT1))
D4: U1.12 (LBO), U3.2 (PD4(XCK/T0))
D5: J1.2, U3.9 (PD5(T1))
D6: J1.3, U3.10 (PD6(AIN0))
D7: U3.11 (PD7(AIN1))
D8: U3.12 (PB0(ICP))
D9: U3.13 (PB1(OC1A))
D10: U3.14 (PB2(SS/OC1B))
D+: X3.A6 (D+), X3.B6 (D+)
D-: X3.A7 (D-), X3.B7 (D-)
DTR: C13.2, J2.6
ENABLE: R13.2, S1.2, U1.11 (EN)
GND: B1.1 (-), C1.2, C2.2, C4.2, C5.-, C6.2, C8.1, C9.1, C10.1, C11.1, C12.1, IC5.1 (GND), J1.6, J2.1, J2.2, J3.1, J3.2, LCD1.7 (VSS), Q2.2, R2.1, R4.1, R5.1, R8.2, R10.1, R16.1, S1.3 (S), S2.3 (2), U1.5 (PGND), U1.6 (PGND), U1.7 (PGND), U1.10 (SYNC), U1.13 (GND), U1.P$18 (PGND), U1.P$19 (PGND), U1.P$20 (PGND), U1.P$21 (PGND), U1.P$22 (PGND), U1.THERMAL (PGND), U2.2 (VSS), U3.3 (GND), U3.5 (AGND), U3.21 (GND), X3.A1B12 (GND), X3.B1A12 (GND)
MISO: U3.16 (PB4(MISO))
MOSI: U3.15 (PB3(MOSI/OC2))
unnamed: L1.P$2 (2), U1.3 (SW), U1.4 (SW)
unnamed: R1.1, R2.2, U1.9 (LBI)
unnamed: R3.1, R4.2, U1.14 (FB)
unnamed: R8.1, U2.5 (PROG)
unnamed: C3.2, LCD1.1 (C2+)
unnamed: C3.1, LCD1.2 (C2-)
unnamed: C7.2, LCD1.3 (C1+)
unnamed: C7.1, LCD1.4 (C1-)
unnamed: C10.2, LCD1.13 (VCOMH)
unnamed: LCD1.12 (IREF), R16.2
unnamed: C9.2, LCD1.14 (VCC)
unnamed: Q2.1, U3.8 (PB7(XTAL2/TOSC2))
unnamed: Q2.3, U3.7 (PB6(XTAL1/TOSC1))
RESET: C13.1, R9.1, U3.29 (PC6(/RESET))
RXI: J2.4, U3.30 (PD0(RXD))
SBU1: X3.A8 (SBU1)
SBU2: X3.B8 (SBU2)
SCK: U3.17 (PB5(SCK))
TXO: J2.5, U3.31 (PD1(TXD))
VBAT: B1.2 (+), C1.1, C4.1, L1.P$1 (1), R1.2, R13.1, U1.8 (VBAT), U2.3 (VBAT)
VBREF: LCD1.6 (VBREF)
VDD1: C6.1, U2.4 (VDD), X3.A4B9 (VBUS), X3.B4A9 (VBUS)

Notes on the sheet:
See Pg 15 1st para
6.8uH power w/2A current
R2 < 500K R1 = 5.5*R2 (3.2V LBO)
R4 = 200K R3 = 1.85Mohm
2.0K = 500mA
CHARGING CIRCUIT
SHUTTER BUTTON
ON/OFF SWITCH
I2C CONNECTOR
BOOST CONVERTER
MICROCONTROLLER
OLED DISPLAY

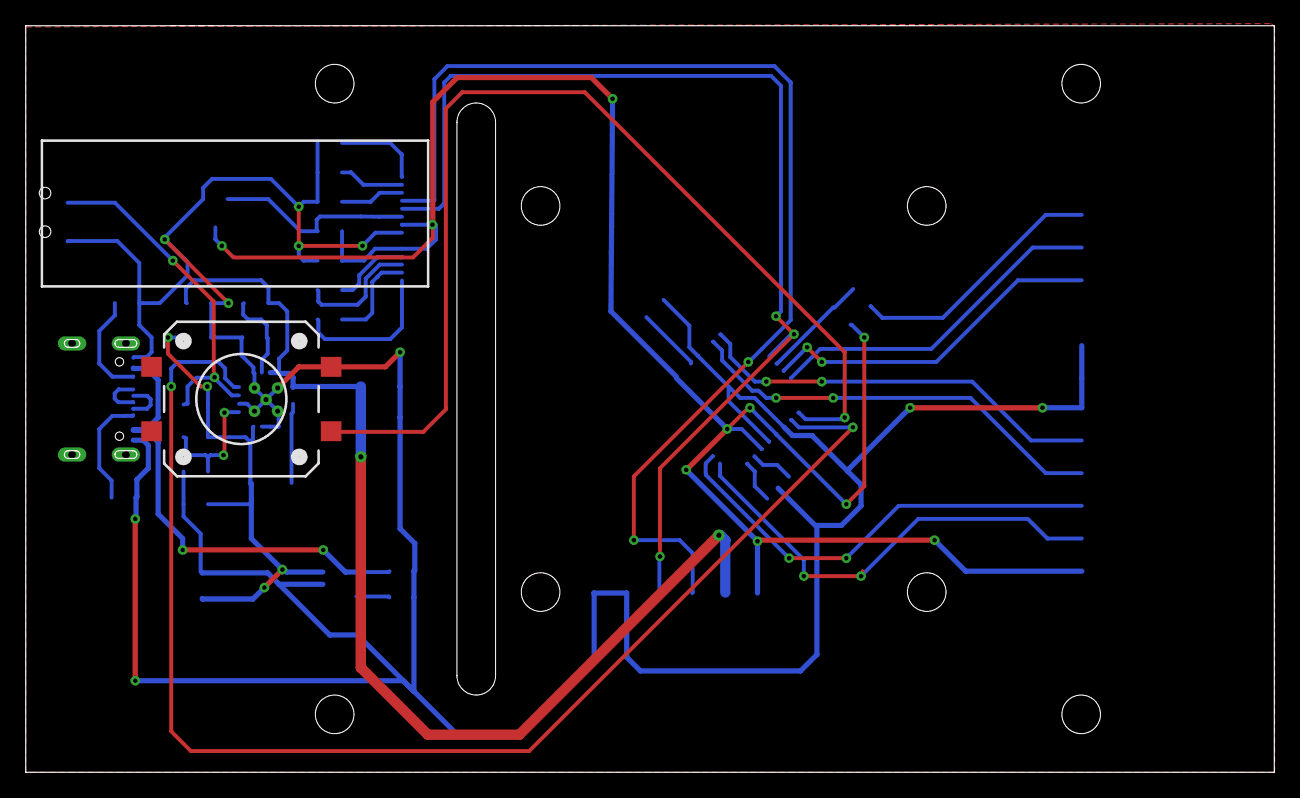
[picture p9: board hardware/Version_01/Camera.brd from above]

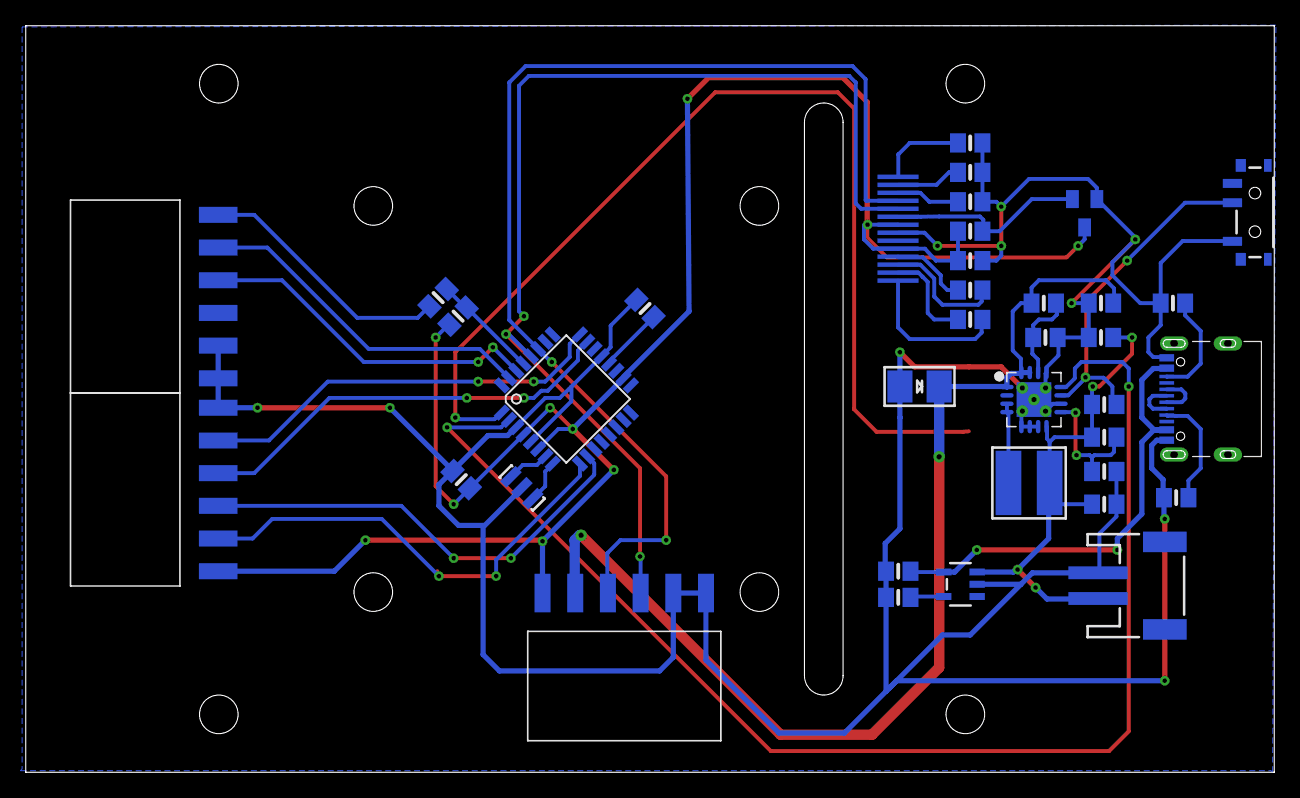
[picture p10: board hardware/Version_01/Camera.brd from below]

Board: 2 copper layers, 97.0 x 58.0 mm, 39 parts (36 on the bottom side), 37 nets.

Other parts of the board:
U$9: PHOENIX_LOGO

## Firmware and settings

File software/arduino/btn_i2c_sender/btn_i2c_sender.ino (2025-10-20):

#include <Wire.h>

#define BTN_PIN 3

byte address = 0x08;

bool buttonValue = 0;
bool lastButtonValue = 0;

void setup() {
  Wire.begin(address);
  pinMode(BTN_PIN, INPUT_PULLUP);
}

void loop() {
  buttonValue = digitalRead(BTN_PIN);

  if (!buttonValue && lastButtonValue) {
    Wire.beginTransmission(address);  
    Wire.write(0);     
    Wire.endTransmission();
    delay(250);
  }

  lastButtonValue = buttonValue;
}

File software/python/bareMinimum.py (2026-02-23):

from picamera2 import Picamera2, Preview
from libcamera import Transform
from PIL import Image
import numpy as np
import time
from board import SCL, SDA #another i2c library needed to interface with the small $
import busio #i2c for small oled
from PIL import Image, ImageDraw, ImageFont #small oled
import adafruit_ssd1306 #small oled

import smbus
bus =  smbus.SMBus(11)
address = 0x08

shutterFlag = True

#------Load Camera
picam2 = Picamera2()

#------Configure Camera
config = picam2.create_preview_configuration(
    main={"size": (480, 800), "format": "BGR888"},
    transform=Transform(hflip=True, vflip=True)
)
picam2.configure(config)

#------Configure small Oled
# Create the I2C interface.
i2c = busio.I2C(SCL, SDA)
# to the right size for your display!
disp = adafruit_ssd1306.SSD1306_I2C(128, 32, i2c)

#------Create image canvas
disp.fill(0)
disp.show()
width = disp.width
height = disp.height
image = Image.new("1", (width, height))

# Get drawing object to draw on image.
draw = ImageDraw.Draw(image)
#font = ImageFont.load_default()
font = ImageFont.truetype('/home/pi/Documents/camera/ESKlarheitGrotesk-Bold.ttf', 20)
aperture = "F2.7"

#------Warm up DRM (forces modeset on first boot so colour format is correct)
picam2.start_preview(Preview.DRM, x=0, y=0, width=480, height=800)
picam2.start()
time.sleep(1)
picam2.stop()
picam2.stop_preview()
time.sleep(1)
picam2.configure(config)

#------Start Camera
picam2.start_preview(Preview.DRM, x=0, y=0, width=480, height=800)
picam2.start()
#picam2.set_controls({"AwbEnable": False})

#------Overlay Laden
#overlay_image = Image.open("Documents/camera/uiImage.png").convert("RGBA")
#overlay_array = np.array(overlay_image)

# Overlay hinzufügen
#picam2.set_overlay(overlay_array)

#-------Draw on small OLED
while shutterFlag:
    draw.rectangle((0, 0, width, height), outline=0, fill=0)
    draw.text((width/4+40,height/4+12), aperture, font=font, fill=255, anchor="mm")
    disp.image(image)
    disp.show()
    time.sleep(1)

input("Press Enter to stop...")
draw.rectangle((0, 0, width, height), outline=0, fill=0)
disp.image(image)
disp.show()

picam2.stop()

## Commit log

2021-03-15 Added hardware and software files
    [Camera.brd, Camera.sch]
2022-03-10 Updated schematic
    [Camera.brd, Camera.sch, PCB_final.dxf]
2022-03-11 Updated the schematic
2024-04-23 Latest version
    [Camera.brd]
2025-10-20 Latest Version V03
    [BOM.xlsx, Camera.brd, Camera.sch]
2025-10-20 Added Arduino file
2025-10-21 Version 3 for production
    [BOM.xlsx, Camera.brd, Camera.sch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]
2026-02-23 Add autostart, i2c fix, color correction for picamera2 DRM preview
    - Set stream format to XRGB8888 to match HyperPixel DRM plane byte order
    - Disable AWB (AwbEnable: False) to prevent color gains from causing apparent R/B channel swap
    - Add systemd service (camera.service) with WorkingDirectory=/home/pi so lgpio can create temp files on boot
    - Add udev rule (99-i2c-alias.rules) to persist /dev/i2c-1 -> /dev/i2c-11 symlink across reboots
    - Add README documenting setup, known issues, and deployment steps
    [bareMinimum.py]

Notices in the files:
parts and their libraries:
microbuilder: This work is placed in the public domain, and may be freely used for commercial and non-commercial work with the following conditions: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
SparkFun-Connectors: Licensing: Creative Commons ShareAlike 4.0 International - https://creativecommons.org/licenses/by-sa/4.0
